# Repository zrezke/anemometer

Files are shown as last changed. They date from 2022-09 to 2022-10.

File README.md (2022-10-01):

# Anemometer V1

The anemometer V1 is a fully open source hand held wind speed measuring device intended for low accuracy applications.

<div align="center">
  
  &nbsp
  
</div>

If you have a 3d printer everything else needed to build this device is commonly available.

Check out the demo video:
<a href="https://www.youtube.com/watch?v=-xksoXeRDyU" target="_blank">

</a>

Measured wind speed (not average wind speed) was varying from $2.66m/s$ to $6.54m/s$, mostly it was showing $3.95 m/s$ or $5.25m/s$. I think the results are acceptable because there were definitely some lulls and gusts and the wind speed wasn't averaged.

Actual **average wind speed** at the time of measuring was about $5.8 m/s$  
Source:

- https://monitor.protezionecivile.fvg.it/#/misure/69/6
- Time of measuring: 24.09.2022 @13:56.
- Location: Grado, Italy

## Parts List

| Part | Quantity | Link |
| --- | --- | --- |
| (3x3) mm neodymium magnet | 3 | https://neodim-magneti.si/shop/neodim-magneti/okrogli-magneti/magneti-neodim-3-x-3-mm-okrogli/ |
| 8mm aluminum shaft | 1 | ... |
| 607zz bearing | 2 | ... |
| ESP32 devboard | 1 | https://www.aliexpress.com/item/4000090521976.html?10000012530088478 |
| TLE4905L hall effect sensor (switcher) | 1 (it's easy to break the legs so maybe order a few) | https://www.ic-elect.si/ic-tle4905l-to-92slim-switcher.html |
| Self drilling screw | 4 | I used Ø4mm, 3cm long ones I found at home. Something like [this](https://si.farnell.com/tr-fastenings/4-2-x-22-kpa2dx-s50-din7504/countersunk-head-screw-ss-4-2mm/dp/3442592) should work. |

## Overview (Basic functioning principle)

The wind drives the cups and causes the shaft to rotate at a speed proportional to the wind speed. Three magnets are mounted around the shaft and a [hall effect sensor](https://en.wikipedia.org/wiki/Hall_effect_sensor) detects each time a magnet passes by. Based on the number of pulses, wind speed can be calculated.

## Overview (hardware)

### Body

The body is composed of two parts.
The lower part is bigger and stores the esp32 and battery. On the side it has a canal for cable routing.
The upper part serves as a mounting point for the two 607zz bearings into which the shaft is inserted. (one bearing at the bottom and one on top)  
It also has a canal on the side for the hall effect sensor it's cables.  
The two parts are connected with 4 screws.

<div align="center">
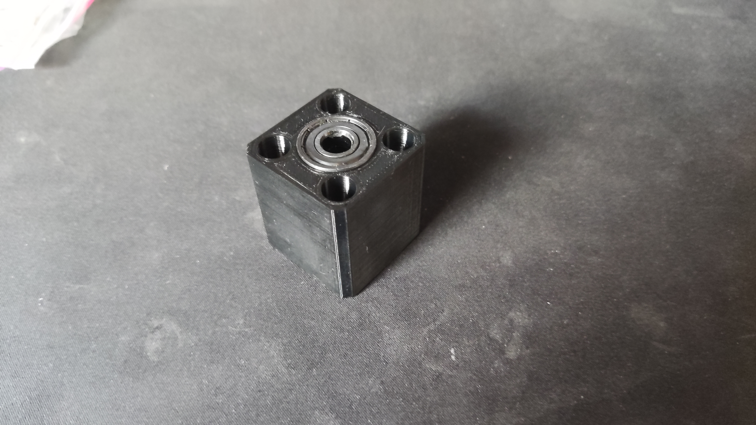
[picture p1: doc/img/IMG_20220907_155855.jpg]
  
  &nbsp
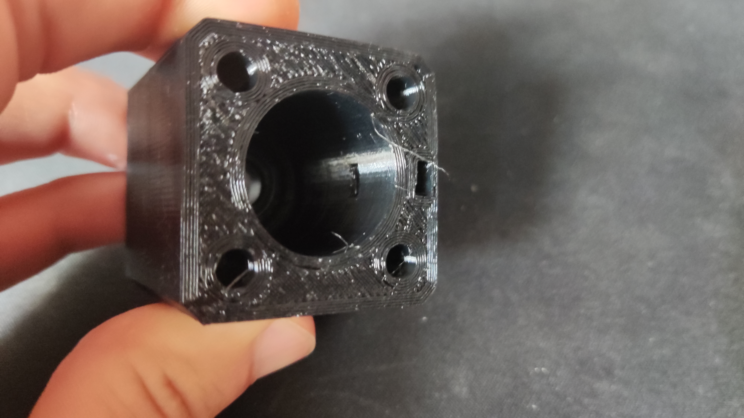
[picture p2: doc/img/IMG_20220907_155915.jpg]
  
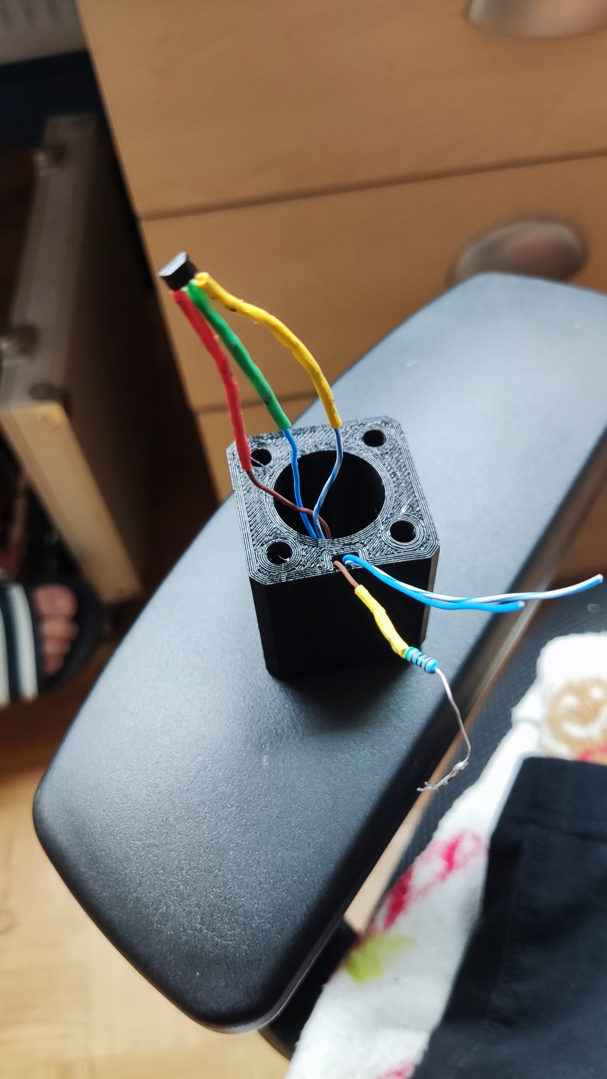
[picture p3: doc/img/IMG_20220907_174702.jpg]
  
</div>
<div align="center">
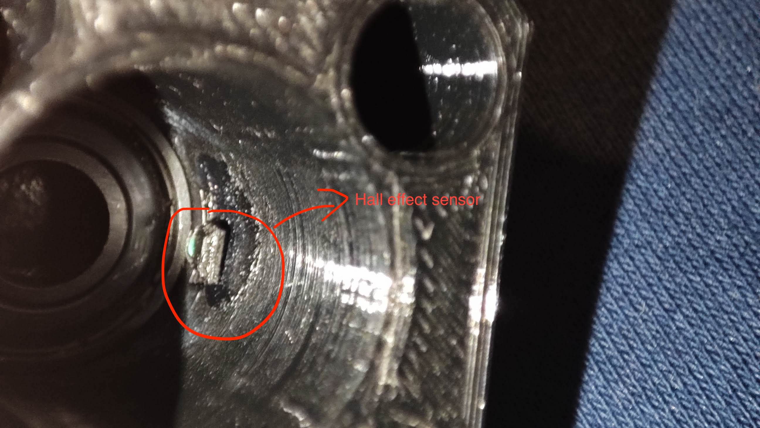
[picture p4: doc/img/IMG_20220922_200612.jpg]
  
  &nbsp
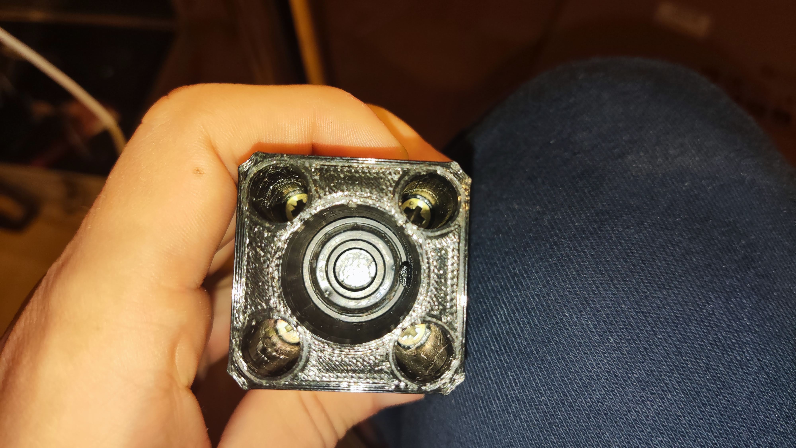
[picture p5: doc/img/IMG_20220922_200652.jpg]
  
</div>

### Cups

The cups are modeled after the conical 60/40 cups in this paper: https://www.researchgate.net/publication/229017042_On_Cup_Anemometer_Rotor_Aerodynamics

<div align="center">
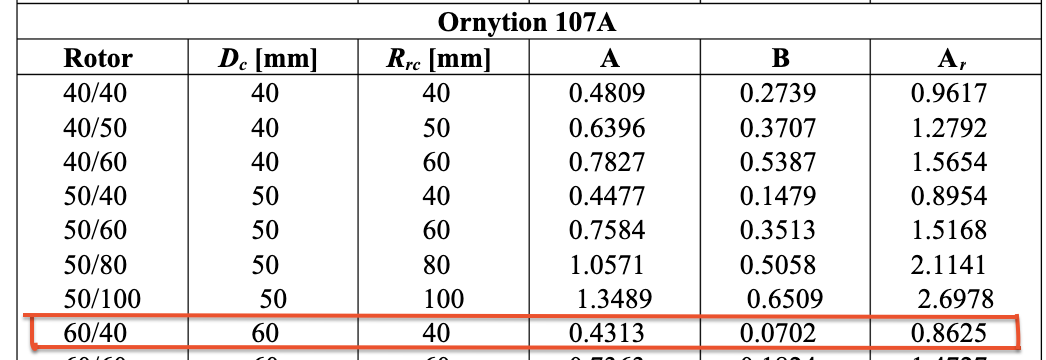
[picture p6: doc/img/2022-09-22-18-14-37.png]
  
  &nbsp
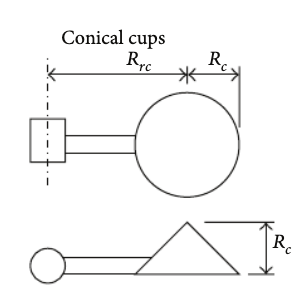
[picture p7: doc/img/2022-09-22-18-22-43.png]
https://www.researchgate.net/publication/259530558_Aerodynamic_Analysis_of_Cup_Anemometers_Performance_The_Stationary_Harmonic_Response
  
</div>

They are printed individually and then super glued to a 3d printed tube that slides onto the aluminum shaft.

<div align="center">
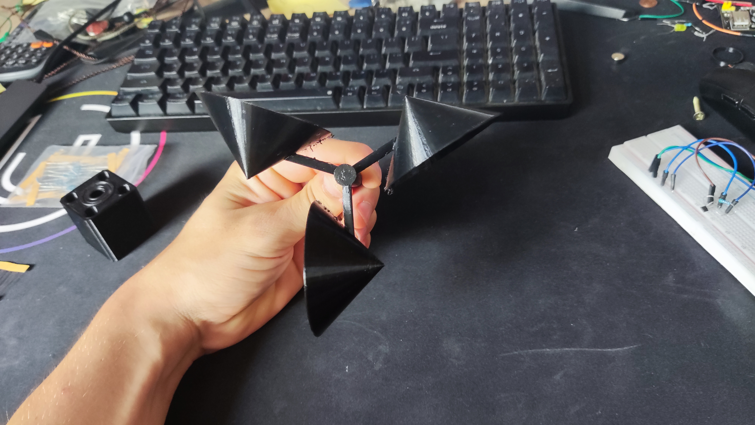
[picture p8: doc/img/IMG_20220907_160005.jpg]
  
  &nbsp
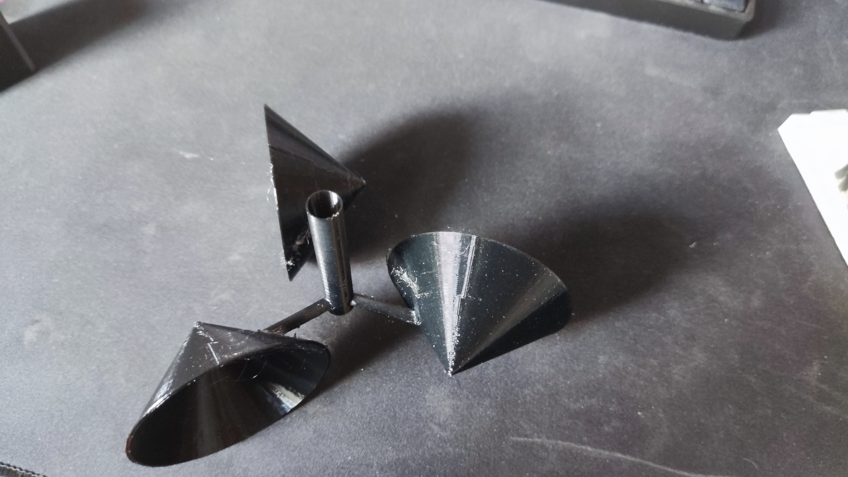
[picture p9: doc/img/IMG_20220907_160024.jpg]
  
</div>

### Magnets

The three magnets are placed and glued on a holder that is then slid onto the shaft.  
It is important to orient the magnets correctly so the sensor can detect them. (Hall effect sensor is sensitive to the direction of the magnetic field)

<div align="center">
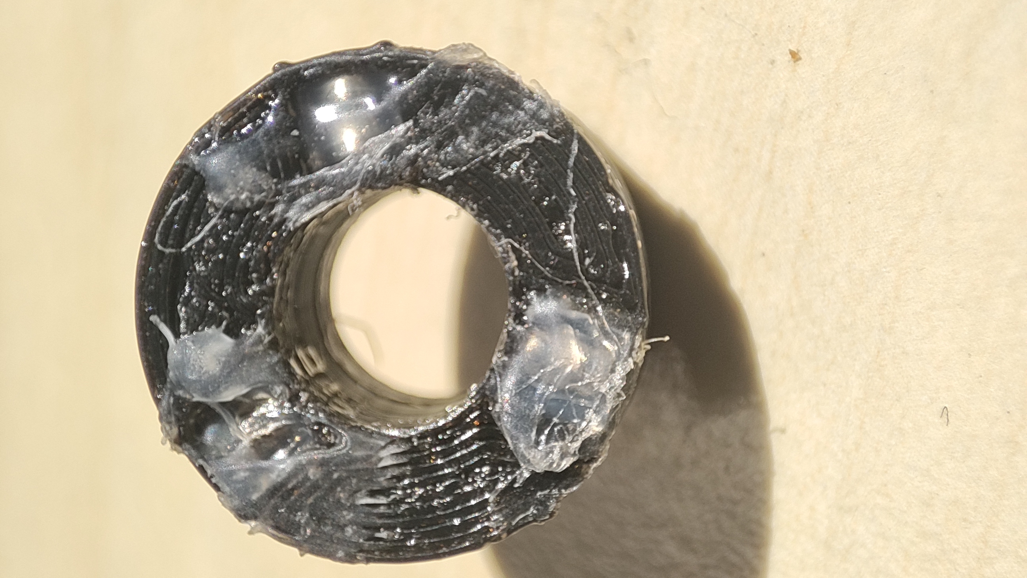
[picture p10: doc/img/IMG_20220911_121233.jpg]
  
  &nbsp
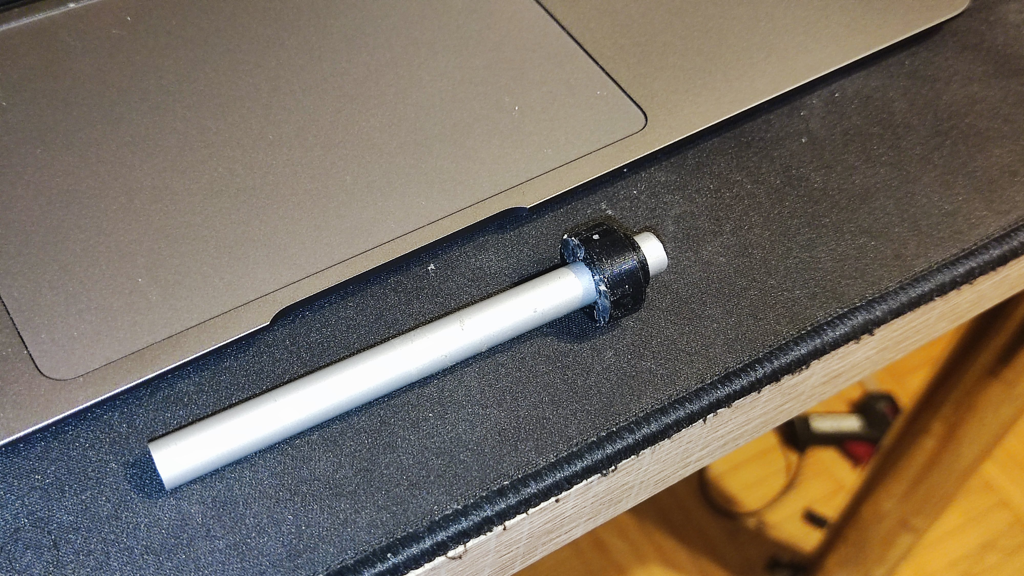
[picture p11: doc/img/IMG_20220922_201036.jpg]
  
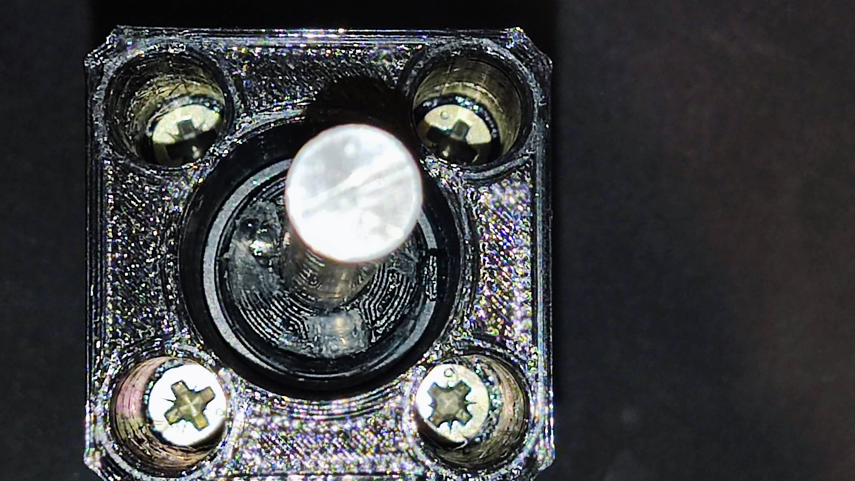
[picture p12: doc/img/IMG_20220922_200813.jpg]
  
</div>

### Electronics

The 4905L hall effect sensor has $3$ pins, $Vs\space (power),\space GND,\space Q\space (output)$. A pull up resistor is connected between $Vs$ and $Q$. When a magnet passes by the sensor pulls the $Q$ pin low.  
The sensor output $Q$ is connected to $GPIO\space 27$ on the ESP32 devboard. $GPIO\space 26$ is connected to $LOW$ as it is a control pin for the counter that is used to count rotations per second. $GPIO\space26 = LOW$, means the counter is enabled (counts).
$Vs$ is connected to $5V$ and $GND$ is connected to ground.
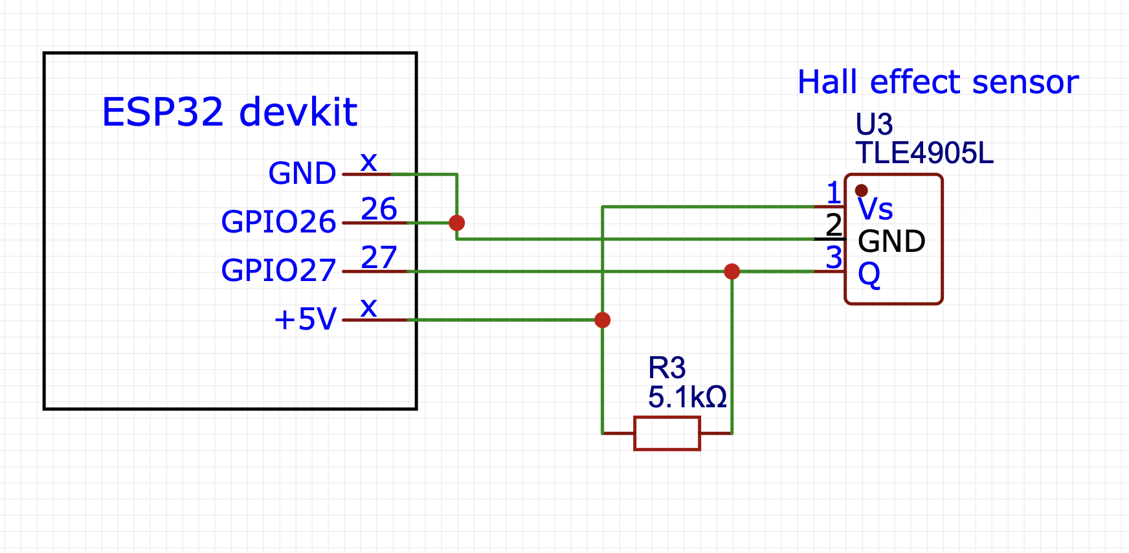
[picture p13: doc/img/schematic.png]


## Overview (software)

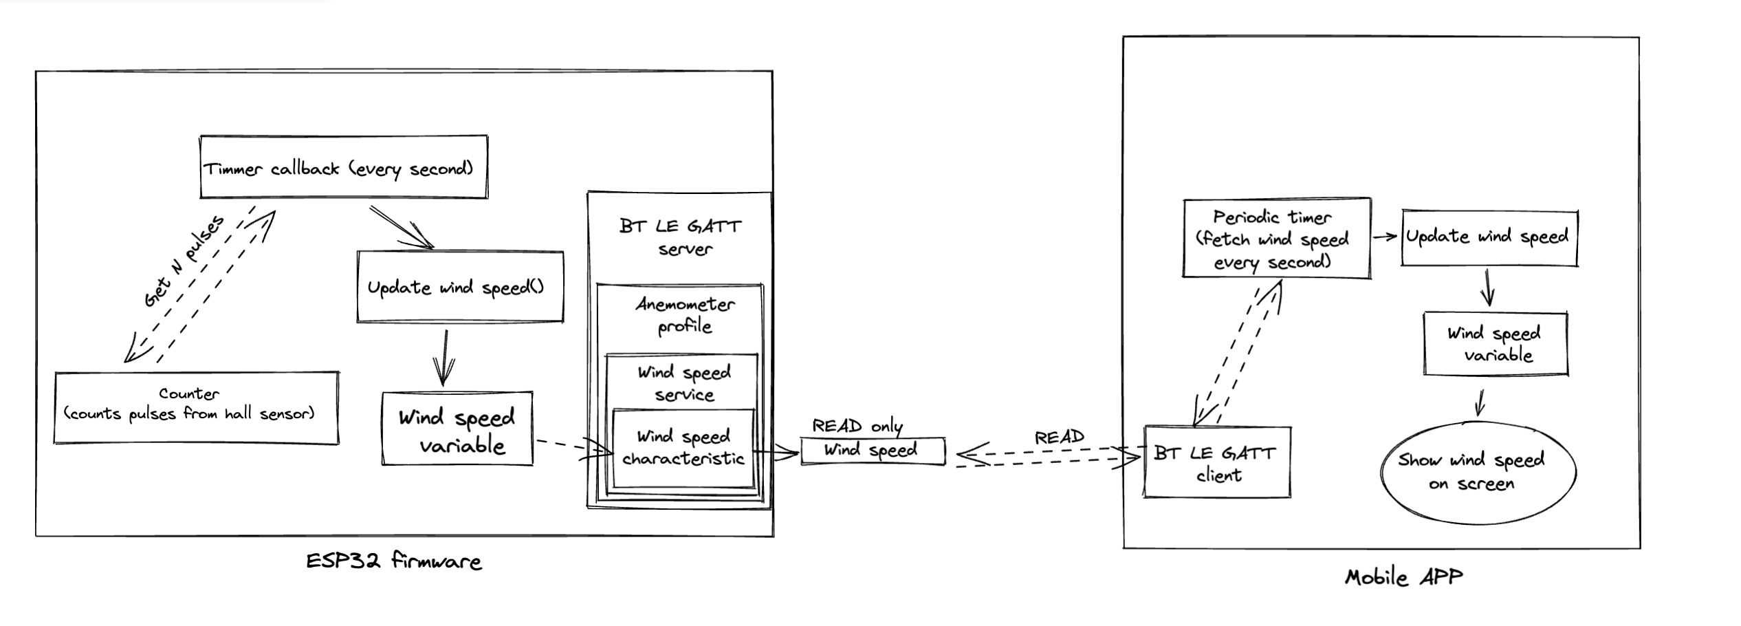
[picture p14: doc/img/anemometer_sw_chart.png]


### Firmware

The firmware is written in C and uses the esp-idf framework.  
It handles detection of rotations per second based on the sensor input, then calculating wind speed based on that. To expose data to the client application it uses a Bluetooth Low Energy GATT server.

To detect rotations per second, a counter is configured on GPIO27 to count on falling edge with a max count of $3$.
When max count is reached a full rotation has completed (because there are three magnets around the shaft), an interrupt is triggered. The interrupt handler queues a task to increment the `current_second_rotations` variable (variable that stores how many times the shaft has rotated in currently ongoing second). It is important to use a freeRTOS task queue to avoid blocking other processes and triggering the watchdog. (https://stackoverflow.com/questions/66278271/task-watchdog-got-triggered-the-tasks-did-not-reset-the-watchdog-in-time)
All tasks in the queue get processed before the **timer** interrupt is triggered. The timer interrupt triggers every second, it assigns `current_second_rotations` to the `rotation_frequency` variable (rotations/second) and resets the `current_second_rotations` variable.

Once we have the `rotation_frequency` we can calculate the wind speed using the formula:

$$ V = A f + B $$

... where $A$ and $B$ are calibration coefficients, $V$ is wind speed and $f$ is the anemometer's _rotation frequency output_ (**not rotation frequency**).  
$A$ and $B$ are normally determined experimentally in a wind tunnel. But since we are using this device for low accuracy applications we use the coefficients from Ornytion 107A anemometer when it's used with 60/40 cups (that's what the cups are modeled after).

https://www.researchgate.net/publication/259530558_Aerodynamic_Analysis_of_Cup_Anemometers_Performance_The_Stationary_Harmonic_Response

To expose data to the client application a Bluetooth Low Energy GATT server is set up.
As seen in the chart above, the GATT server has an Anemometer profile with a wind speed service that exposes the wind speed characteristic as READ only.

<div align="center">
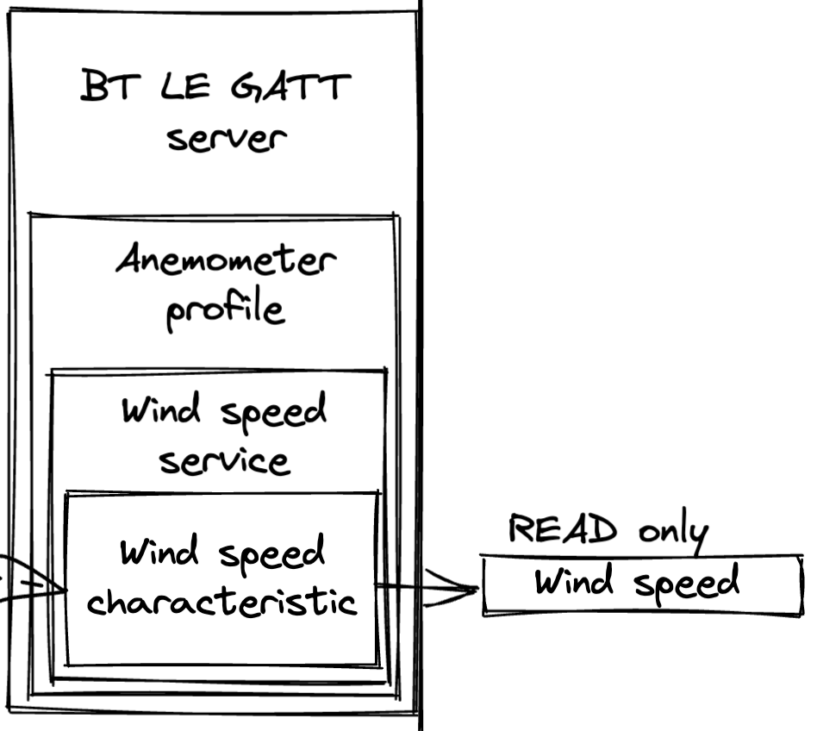
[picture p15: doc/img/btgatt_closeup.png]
  
</div>
The firmware also configures BT LE GAP for advertising.
If you want to learn about BT LE GATT and GAP I recommend reading these two articles:

- https://learn.adafruit.com/introduction-to-bluetooth-low-energy/gap
- https://learn.adafruit.com/introduction-to-bluetooth-low-energy/gatt

If you want to include BT LE with esp-idf in your own projects there are examples available in the esp-idf repository:

- https://github.com/espressif/esp-idf/blob/82cbcf893a/examples/bluetooth/bluedroid/ble/gatt_server_service_table/tutorial/Gatt_Server_Service_Table_Example_Walkthroug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
  This article also helped me a lot to clear a few things up:
- https://atadiat.com/en/e-all-about-esp32-part-4/

### Mobile app

The app is written in dart (flutter).  
It serves as the BT LE client for the anemometer and displays the wind speed.
The [flutter_blue_plus](https://pub.dev/packages/flutter_blue_plus) package does all the heavy lifting for you.

<div align="center">
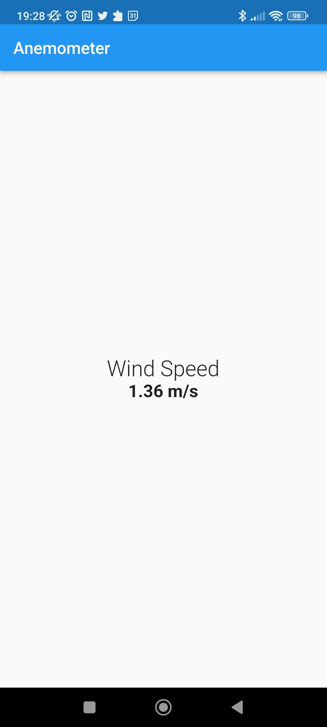
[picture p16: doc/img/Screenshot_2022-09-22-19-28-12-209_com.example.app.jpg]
  
  &nbsp
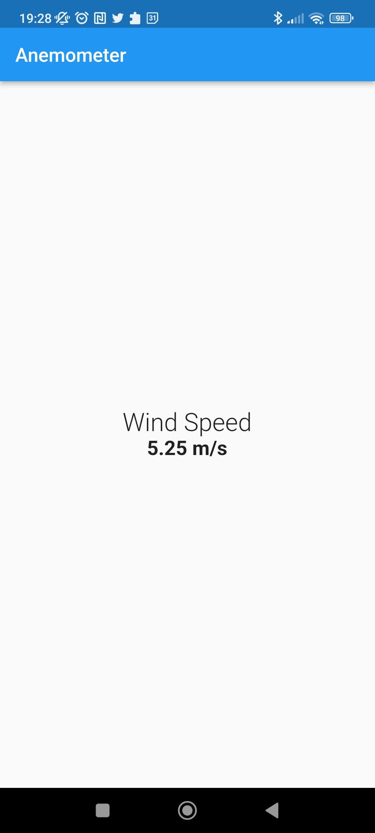
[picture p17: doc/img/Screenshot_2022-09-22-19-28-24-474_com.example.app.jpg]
  
</div>

## How to build and run

### Firmware

- Install _esp-idf_:
  - [Windows](https://docs.espressif.com/projects/esp-idf/en/latest/esp32/get-started/windows-setup.html)
  - [Linux/MacOS](https://docs.espressif.com/projects/esp-idf/en/latest/esp32/get-started/linux-macos-setup.html)
- Open a terminal (needs to have `idf.py` available) and navigate to the firmware directory
- Connect board to computer
- RUN `idf.py flash`

### Mobile app

- Install flutter
- Navigate to the app directory
- RUN `flutter build apk && flutter install` or `flutter run` if you only want to run it and not install.

## What's next

I want to create Anemometer V2, which will be a more compact and an all around better version of this one.

### Goals for V2:

- Custom PCB with a much smaller footprint
- Smaller cups and shaft setup with less resistance.
  - Also put a cage around the cups so you can throw this device in a backpack and not worry about it.
- Maybe move to a different platform (ESP32 seems to be overkill for this application)
- Add battery and charging circuit (USB C)

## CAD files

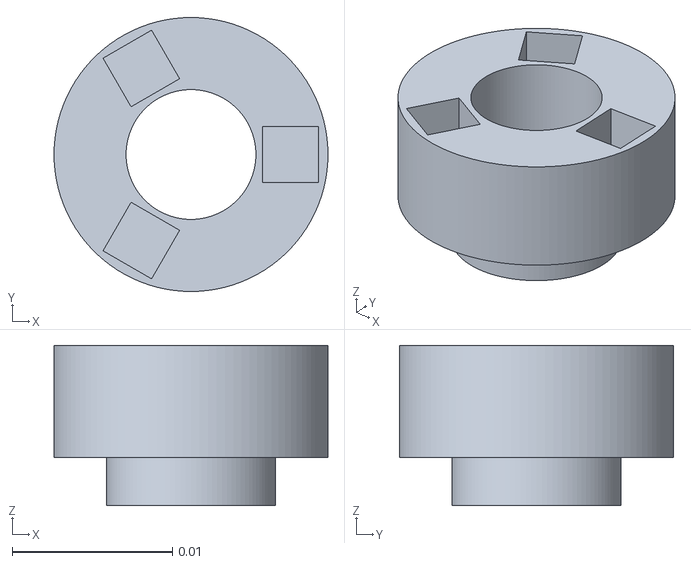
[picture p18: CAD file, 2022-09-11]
3dprint/magnet-holder.stl
0.0171 x 0.0171 x 0.01

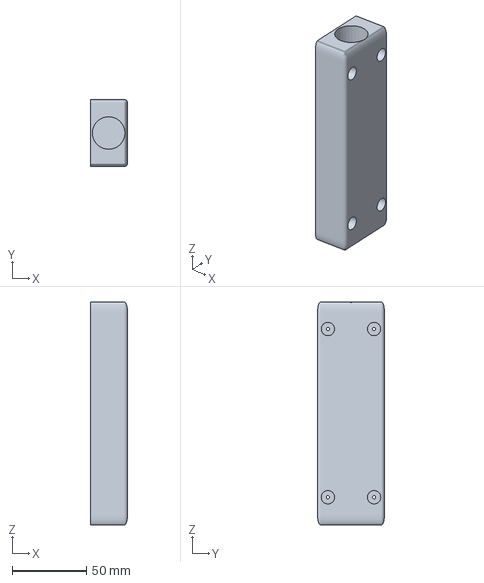
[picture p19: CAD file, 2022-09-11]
3dprint/housing-side2.3mf
25.0 x 45.0 x 150.0 mm

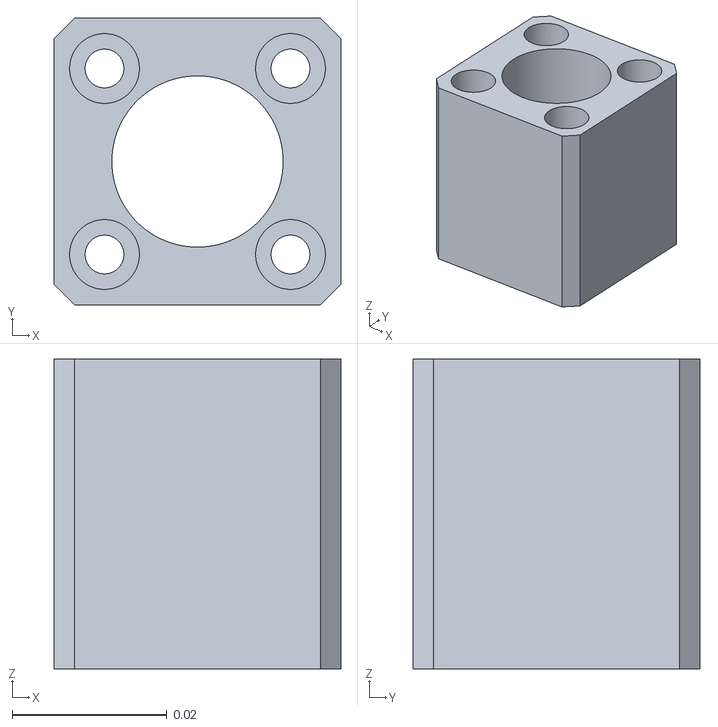
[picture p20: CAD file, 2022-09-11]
3dprint/housingv2-upper.stl
0.037 x 0.037 x 0.04

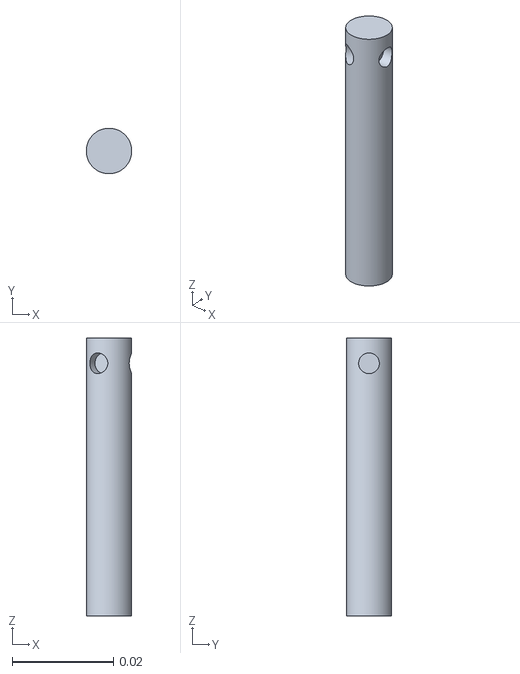
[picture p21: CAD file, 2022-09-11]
3dprint/rotor-shaft.stl
0.009 x 0.009 x 0.055

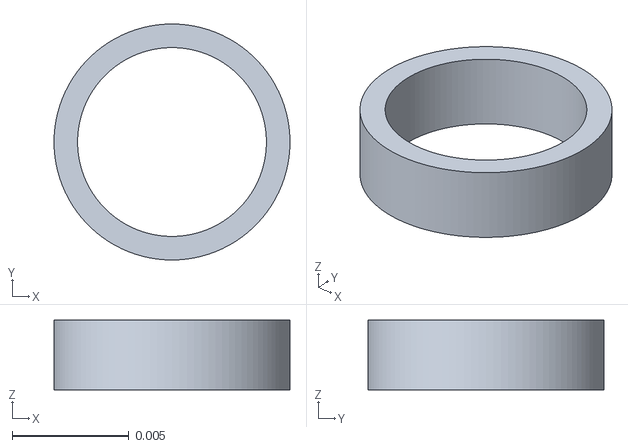
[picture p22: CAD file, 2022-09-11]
3dprint/8mm.stl
0.0101 x 0.0101 x 0.003

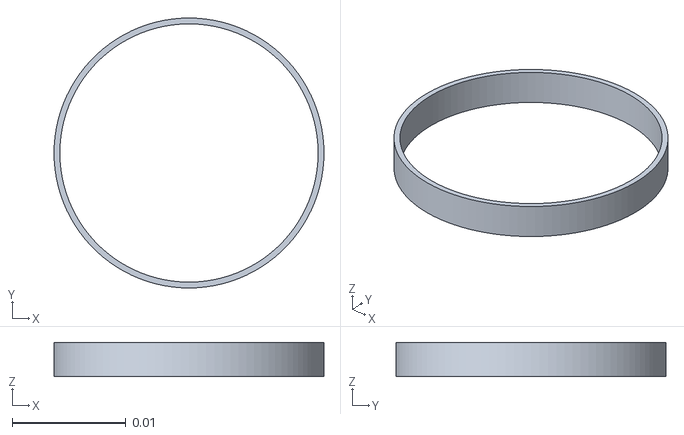
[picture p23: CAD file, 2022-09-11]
3dprint/test-hole.stl
0.0237 x 0.0237 x 0.003

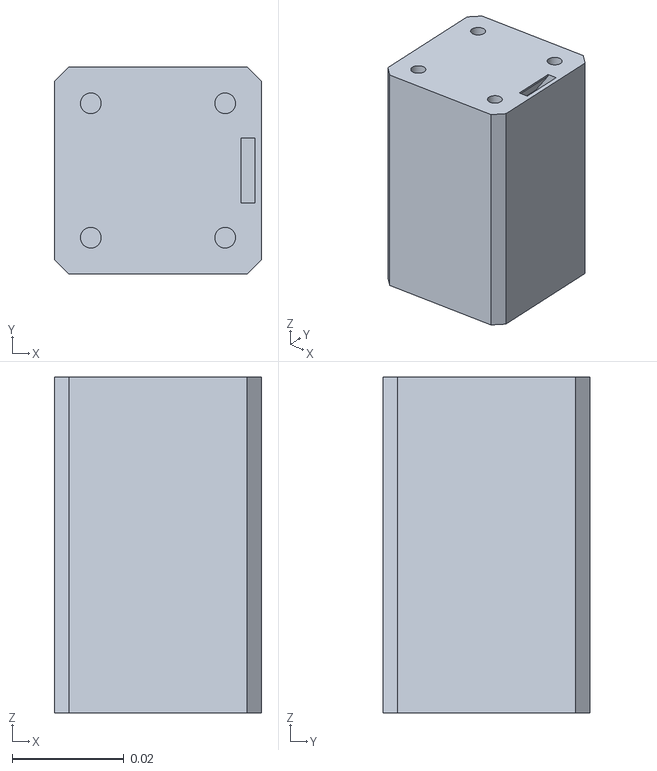
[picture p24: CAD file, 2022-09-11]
3dprint/housing-v2-lower.stl
0.037 x 0.037 x 0.06

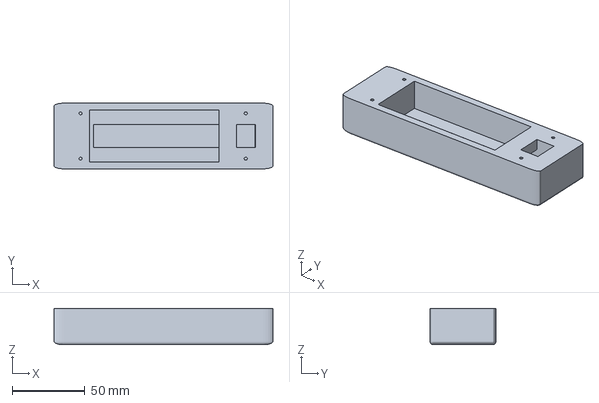
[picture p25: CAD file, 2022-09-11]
3dprint/housing-side1.3mf
150.0 x 45.0 x 25.0 mm

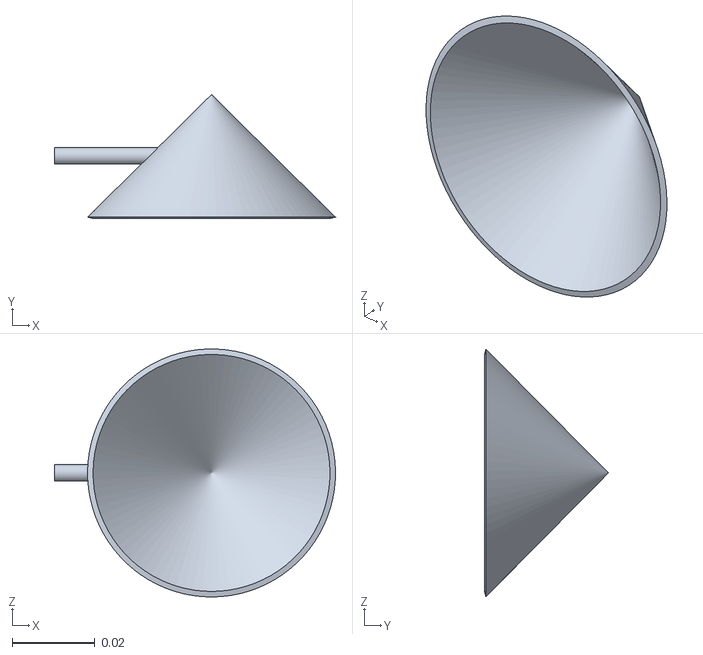
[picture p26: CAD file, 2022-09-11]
3dprint/rotor-cup-w-hand.stl
0.068 x 0.03 x 0.06

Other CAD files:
3dprint/8mm.blend
3dprint/cones.blend
3dprint/housing-side1.stl
3dprint/housing-side2.stl
3dprint/housing-v2.blend
3dprint/housing.blend
3dprint/magnet-holder.blend
3dprint/test-hole.blend

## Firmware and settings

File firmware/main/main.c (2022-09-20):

#include <stdio.h>
#include <string.h>
#include "sdkconfig.h"
#include <time.h>
#include "driver/gpio.h"
#include "driver/pcnt.h"
#include "anemometer.h"
#include "driver/timer.h"
#include "freertos/FreeRTOS.h"
#include "freertos/task.h"
#include "freertos/queue.h"

#include "freertos/event_groups.h"
#include "esp_system.h"
#include "esp_log.h"
#include "nvs_flash.h"
#include "esp_bt.h"

#include "esp_gap_ble_api.h"
#include "esp_gatts_api.h"
#include "esp_bt_defs.h"
#include "esp_bt_main.h"
#include "esp_bt_main.h"

#include "anemometer_bt_profile.h"
#include "btle_gap.h"
#include "btle_gatt.h"

#define GATTS_TABLE_TAG "GATTS TABLE TAG"
typedef struct
{
  bool update;
} timer_event_t;
typedef struct
{
  bool update;
} counter_event_t;

static xQueueHandle s_timer_queue;
static xQueueHandle s_counter_queue;

pcnt_config_t pulse_counter_config = {
    .unit = PCNT_UNIT_0,
    .channel = PCNT_CHANNEL_0,
    .pulse_gpio_num = GPIO_NUM_27,
    .ctrl_gpio_num = GPIO_NUM_26,
    .lctrl_mode = PCNT_MODE_KEEP,
    .hctrl_mode = PCNT_MODE_DISABLE,
    .neg_mode = PCNT_COUNT_INC,
    .pos_mode = PCNT_COUNT_DIS,
    .counter_l_lim = 0,
    .counter_h_lim = N_PULSES_PER_REV};

static void IRAM_ATTR pcnt_h_lim_interrupt_handler(void *arg)
{

  // pcnt_counter_pause(pulse_counter_config.unit);
  // pcnt_counter_clear(pulse_counter_config.unit);
  // pcnt_counter_resume(pulse_counter_config.unit);
  counter_event_t evt = {
      .update = true};
  xQueueSendFromISR(s_counter_queue, &evt, NULL);
}

void start_counter()
{
  // configure pcnt
  pcnt_unit_config(&pulse_counter_config);
  // register max val interrupt
  pcnt_event_enable(pulse_counter_config.unit, PCNT_EVT_H_LIM);
  pcnt_isr_service_install(0);
  pcnt_isr_handler_add(PCNT_UNIT_0, pcnt_h_lim_interrupt_handler, NULL);
  pcnt_counter_pause(pulse_counter_config.unit);
  pcnt_counter_clear(pulse_counter_config.unit);
  pcnt_counter_resume(pulse_counter_config.unit);
}

#define TIMER_DIVIDER (16)
#define TIMER_SCALE (TIMER_BASE_CLK / TIMER_DIVIDER)

const timer_group_t TIMER_GROUP = TIMER_GROUP_0;
const timer_idx_t TIMER_INDEX = TIMER_0;
const int ONE_SECOND = 1;

void update_rotation_frequency()
{
  rotation_frequency = current_second_rotations;
  current_second_rotations = 0;
}

static bool IRAM_ATTR timer_isr_callback(void *arg)
{
  BaseType_t high_task_awoken = pdFALSE;
  uint64_t timer_counter_value = timer_group_get_counter_value_in_isr(TIMER_GROUP, TIMER_INDEX);
  timer_event_t evt = {
      .update = true,
  };
  xQueueSendFromISR(s_timer_queue, &evt, &high_task_awoken);
  return high_task_awoken == pdTRUE;
}

timer_config_t timer_config = {
    .divider = TIMER_DIVIDER,
    .counter_dir = TIMER_COUNT_UP,
    .counter_en = TIMER_START,
    .alarm_en = TIMER_ALARM_EN,
    .auto_reload = true};

void start_timer()
{
  timer_init(TIMER_GROUP, TIMER_INDEX, &timer_config);
  timer_set_counter_value(TIMER_GROUP, TIMER_INDEX, 0);
  timer_set_alarm_value(TIMER_GROUP, TIMER_INDEX, ONE_SECOND * TIMER_SCALE);
  timer_enable_intr(TIMER_GROUP, TIMER_INDEX);

  timer_isr_callback_add(TIMER_GROUP, TIMER_INDEX, timer_isr_callback, NULL, 0);
  timer_start(TIMER_GROUP, TIMER_INDEX);
}

void handleCounterQueue()
{
  counter_event_t counter_event;
  portBASE_TYPE cnt_res;

  while (true)
  {
    cnt_res = xQueueReceive(s_counter_queue, &counter_event, 0);
    if (cnt_res == pdFALSE)
    {
      return;
    }
    current_second_rotations++;
  }
}

static const uint16_t primary_service_uuid = ESP_GATT_UUID_PRI_SERVICE;
static const uint16_t character_declaration_uuid = ESP_GATT_UUID_CHAR_DECLARE;
static const uint8_t char_prop_read = ESP_GATT_CHAR_PROP_BIT_READ;
static const uint16_t character_client_config_uuid = ESP_GATT_UUID_CHAR_CLIENT_CONFIG;

#define CHAR_DECLARATION_SIZE (sizeof(uint8_t))
static const uint16_t GATTS_CHAR_UUID_TEST_A = 0xFF01;
#define GATTS_DEMO_CHAR_VAL_LEN_MAX 500
static const uint8_t heart_measurement_ccc[2] = {0x00, 0x00};
// static const uint8_t char_value[4] = {0x11, 0x22, 0x33, 0x44};

// static const uint8_t wind_speed[sizeof(float)];
static union
{
  float value;
  uint8_t bytes[4];
} wind_speed;

/// Full HRS Database Description - Used to add attributes into the database
static const esp_gatts_attr_db_t anemometer_gatt_db[WIND_SPEED_NUMBER_OF_CHARACTERISTICS] =
    {
        // Heart Rate Service Declaration
        [WIND_SPEED_SERVICE] =
            {{ESP_GATT_RSP_BY_APP}, {ESP_UUID_LEN_16, (uint8_t *)&primary_service_uuid, ESP_GATT_PERM_READ, sizeof(uint16_t), sizeof(true_wind_speed_service_uuid), (uint8_t *)&true_wind_speed_service_uuid}},

        // Wind speed characteristic declaration
        [WIND_SPEED_CHARACTERISTIC] =
            {{ESP_GATT_RSP_BY_APP}, {ESP_UUID_LEN_16, (uint8_t *)&character_declaration_uuid, ESP_GATT_PERM_READ, CHAR_DECLARATION_SIZE, CHAR_DECLARATION_SIZE, (uint8_t *)&char_prop_read}},

        /* Characteristic Value */
        [WIND_SPEED_CHAR_VAL] =
            {{ESP_GATT_RSP_BY_APP}, {ESP_UUID_LEN_16, (uint8_t *)&GATTS_CHAR_UUID_TEST_A, ESP_GATT_PERM_READ | ESP_GATT_PERM_WRITE, GATTS_DEMO_CHAR_VAL_LEN_MAX, sizeof(wind_speed.bytes), (uint8_t *)wind_speed.bytes}},

        /* Client Characteristic Configuration Descriptor */
        [WIND_SPEED_CFG] =
            {{ESP_GATT_AUTO_RSP}, {ESP_UUID_LEN_16, (uint8_t *)&character_client_config_uuid, ESP_GATT_PERM_READ | ESP_GATT_PERM_WRITE, sizeof(uint16_t), sizeof(heart_measurement_ccc), (uint8_t *)heart_measurement_ccc}},

};

static void gatts_profile_event_handler(esp_gatts_cb_event_t event,
                                        esp_gatt_if_t gatts_if, esp_ble_gatts_cb_param_t *param);

static struct gatts_profile_inst anemometer_profile_tab[ANEMOMETER_PROFILE_NUM] = {
    [ANEMOMETER_PROFILE_APP_IDX] = {
        .gatts_cb = gatts_profile_event_handler,
        .gatts_if = ESP_GATT_IF_NONE, /* Not get the gatt_if, so initial is ESP_GATT_IF_NONE */
    },
};
uint16_t wind_speed_handle_table[WIND_SPEED_NUMBER_OF_CHARACTERISTICS];

static void gatts_profile_event_handler(esp_gatts_cb_event_t event,
                                        esp_gatt_if_t gatts_if, esp_ble_gatts_cb_param_t *param)
{
  ESP_LOGE(GATTS_TABLE_TAG, "event = %x\n", event);
  switch (event)
  {
  case ESP_GATTS_REG_EVT:
  {
    ESP_LOGI(GATTS_TABLE_TAG, "%s %d\n", __func__, __LINE__);
    esp_ble_gap_set_device_name(DEVICE_NAME);
    ESP_LOGI(GATTS_TABLE_TAG, "%s %d\n", __func__, __LINE__);
    esp_ble_gap_config_adv_data(&anemometer_adv_config);
    ESP_LOGI(GATTS_TABLE_TAG, "%s %d\n", __func__, __LINE__);
    esp_ble_gatts_create_attr_tab(anemometer_gatt_db, gatts_if, WIND_SPEED_NUMBER_OF_CHARACTERISTICS, SERVICE_INSTANCE_ID);
    ESP_LOGI(GATTS_TABLE_TAG, "%s %d\n", __func__, __LINE__);
    break;
  }
  case ESP_GATTS_CONNECT_EVT:
  {
    /* For the IOS system, please reference the apple official documents about the ble connection parameters restrictions. */
    esp_ble_conn_update_params_t conn_params = {0};
    memcpy(conn_params.bda, param->connect.remote_bda, sizeof(esp_bd_addr_t));
    conn_params.latency = 0;
    conn_params.max_int = 0x20; // max_int = 0x20*1.25ms = 40ms
    conn_params.min_int = 0x10; // min_int = 0x10*1.25ms = 20ms
    conn_params.timeout = 400;  // timeout = 400*10ms = 4000ms
    ESP_LOGI(GATTS_TABLE_TAG, "ESP_GATTS_CONNECT_EVT, conn_id %d, remote %02x:%02x:%02x:%02x:%02x:%02x:, is_conn %d",
             param->connect.conn_id,
             param->connect.remote_bda[0], param->connect.remote_bda[1], param->connect.remote_bda[2],
             param->connect.remote_bda[3], param->connect.remote_bda[4], param->connect.remote_bda[5]);
    // start sent the update connection parameters to the peer device.
    anemometer_profile_tab[ANEMOMETER_PROFILE_APP_IDX].conn_id = param->connect.conn_id;
    esp_ble_gap_update_conn_params(&conn_params);
    break;
  }
  case ESP_GATTS_CREAT_ATTR_TAB_EVT:
  {
    ESP_LOGI(GATTS_TABLE_TAG, "The number handle =%x\n", param->add_attr_tab.num_handle);
    if (param->add_attr_tab.status != ESP_GATT_OK)
    {
      ESP_LOGE(GATTS_TABLE_TAG, "Create attribute table failed, error code=0x%x", param->add_attr_tab.status);
    }
    else if (param->add_attr_tab.num_handle != WIND_SPEED_NUMBER_OF_CHARACTERISTICS)
    {
      ESP_LOGE(GATTS_TABLE_TAG, "Create attribute table abnormally, num_handle (%d) \
                    doesn't equal to WIND_SPEED_NUMBER_OF_CHARACTERISTICS(%d)",
               param->add_attr_tab.num_handle, WIND_SPEED_NUMBER_OF_CHARACTERISTICS);
    }
    else
    {
      memcpy(wind_speed_handle_table, param->add_attr_tab.handles, sizeof(wind_speed_handle_table));
      esp_ble_gatts_start_service(wind_speed_handle_table[WIND_SPEED_SERVICE]);
      ESP_LOGI(GATTS_TABLE_TAG, "Created handle table successfully.");
    }
    break;
  }
  case ESP_GATTS_READ_EVT:
  {
    ESP_LOGI(GATTS_TABLE_TAG, "GATT_READ_EVT, conn_id %d, trans_id %d, handle %d\n", param->read.conn_id, param->read.trans_id, param->read.handle);
    esp_gatt_rsp_t rsp;
    memset(&rsp, 0, sizeof(esp_gatt_rsp_t));
    memcpy(rsp.attr_value.value, wind_speed.bytes, 4);
    rsp.attr_value.handle = param->read.handle;
    rsp.attr_value.len = 4;
    esp_ble_gatts_send_response(gatts_if, param->read.conn_id, param->read.trans_id,
                                ESP_GATT_OK, &rsp);
    break;
  }
  default:
    break;
  }
}

static void gap_event_handler(esp_gap_ble_cb_event_t event, esp_ble_gap_cb_param_t *param)
{
  ESP_LOGE(GATTS_TABLE_TAG, "GAP_EVT, event %d\n", event);

  switch (event)
  {
  case ESP_GAP_BLE_ADV_DATA_SET_COMPLETE_EVT:
    esp_ble_gap_start_advertising(&anemometer_adv_params);
    break;
  case ESP_GAP_BLE_ADV_START_COMPLETE_EVT:
    // advertising start complete event to indicate advertising start successfully or failed
    if (param->adv_start_cmpl.status != ESP_BT_STATUS_SUCCESS)
    {
      ESP_LOGE(GATTS_TABLE_TAG, "Advertising start failed\n");
    }
    break;
  default:
    break;
  }
}

static void gatts_event_handler(esp_gatts_cb_event_t event, esp_gatt_if_t gatts_if, esp_ble_gatts_cb_param_t *param)
{
  ESP_LOGI(GATTS_TABLE_TAG, "EVT %d, gatts if %d\n", event, gatts_if);

  /* If event is register event, store the gatts_if for each profile */
  if (event == ESP_GATTS_REG_EVT)
  {
    if (param->reg.status == ESP_GATT_OK)
    {
      anemometer_profile_tab[ANEMOMETER_PROFILE_APP_IDX].gatts_if = gatts_if;
    }
    else
    {
      ESP_LOGI(GATTS_TABLE_TAG, "Reg app failed, app_id %04x, status %d\n",
               param->reg.app_id,
               param->reg.status);
      return;
    }
  }

  do
  {
    int idx;
    for (idx = 0; idx < ANEMOMETER_PROFILE_NUM; idx++)
    {
      if (gatts_if == ESP_GATT_IF_NONE || /* ESP_GATT_IF_NONE, not specify a certain gatt_if, need to call every profile cb function */
          gatts_if == anemometer_profile_tab[idx].gatts_if)
      {
        if (anemometer_profile_tab[idx].gatts_cb)
        {
          anemometer_profile_tab[idx].gatts_cb(event, gatts_if, param);
        }
      }
    }
  } while (0);
}

void app_main()
{
  esp_err_t ret;

  // Initialize NVS.
  ret = nvs_flash_init();
  if (ret == ESP_ERR_NVS_NO_FREE_PAGES || ret == ESP_ERR_NVS_NEW_VERSION_FOUND)
  {
    ESP_ERROR_CHECK(nvs_flash_erase());
    ret = nvs_flash_init();
  }
  ESP_ERROR_CHECK(ret);

  esp_bt_controller_config_t bt_cfg = BT_CONTROLLER_INIT_CONFIG_DEFAULT();
  ret = esp_bt_controller_init(&bt_cfg);
  if (ret)
  {
    ESP_LOGE(GATTS_TABLE_TAG, "%s enable controller failed\n", __func__);
    return;
  }

  ret = esp_bt_controller_enable(ESP_BT_MODE_BLE);
  if (ret)
  {
    ESP_LOGE(GATTS_TABLE_TAG, "%s enable controller failed\n", __func__);
    return;
  }

  ESP_LOGI(GATTS_TABLE_TAG, "%s init bluetooth\n", __func__);
  ret = esp_bluedroid_init();
  if (ret)
  {
    ESP_LOGE(GATTS_TABLE_TAG, "%s init bluetooth failed\n", __func__);
    return;
  }
  ESP_LOGI(GATTS_TABLE_TAG, "%s enable bluetooth\n", __func__);
  ret = esp_bluedroid_enable();
  if (ret)
  {
    ESP_LOGE(GATTS_TABLE_TAG, "%s enable bluetooth failed\n", __func__);
    return;
  }

  esp_ble_gatts_register_callback(gatts_event_handler);
  esp_ble_gap_register_callback(gap_event_handler);
  esp_ble_gatts_app_register(ESP_ANEMOMETER_APP_ID);
  s_timer_queue = xQueueCreate(10, sizeof(timer_event_t));
  s_counter_queue = xQueueCreate(10, sizeof(counter_event_t));
  printf("HELLO WORLD\n");
  start_counter();
  start_timer();

  timer_event_t timer_event;
  bool hasElement = false;
  while (true)
  {
    handleCounterQueue();
    hasElement = xQueueReceive(s_timer_queue, &timer_event, 0);
    if (hasElement && timer_event.update)
    {
      update_rotation_frequency();
      // printf("Current second rotations: %d\n", current_second_rotations);
      wind_speed.value = Ar * rotation_frequency + B;
      printf("ROTATIONS: %d, WIND SPEED: %f ", rotation_frequency, wind_speed.value);
      for (int i = 0; i < 4; i++)
      {
        printf("%d", wind_speed.bytes[i]);
        printf("-");
      }
      printf("\n");
    }
  }
}
